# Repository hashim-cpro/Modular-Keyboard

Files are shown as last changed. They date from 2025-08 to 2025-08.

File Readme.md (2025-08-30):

<div align="center">
  <a href="https://hackclub.com/highway">
    
  </a>
  
<h1>60% Modular Keyboard</h1>
</div>

It is a 60% wireless keyboard(bluetooth) also works wired. It has magnetic modules. Currently I only added a Numpad but almost anything could be added in a chain as long as it works on i2c.
it has hotswapable switches, rgb lights for each key, OLED, rotoary encoder, dedicated charging module(1000mah) and a 10000mah battery. Also it is kind of MCU agnostic, you can use any XIAO series MCU with it, for example rp2040 if you don't want bluetooth or nRF52840.
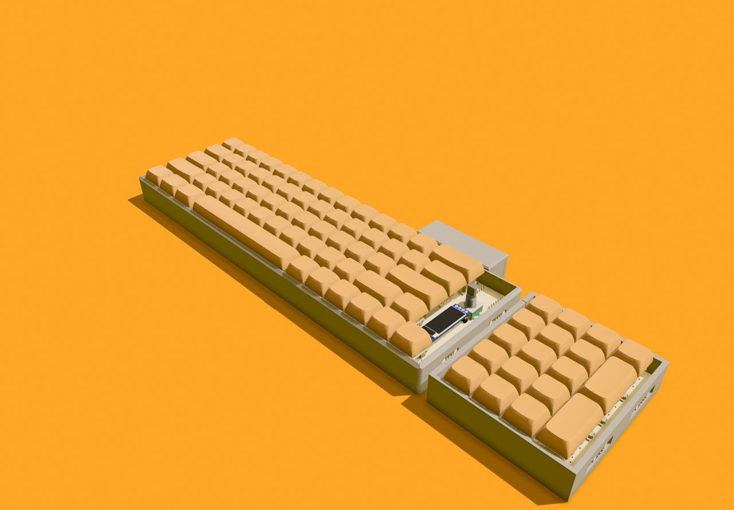
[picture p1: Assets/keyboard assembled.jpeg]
keyboard complete


# CAD Design

I used shapr3d to make the case, it is not done, I am still working on it, once I am happy with a case I will add it here, but the current case is as follows:
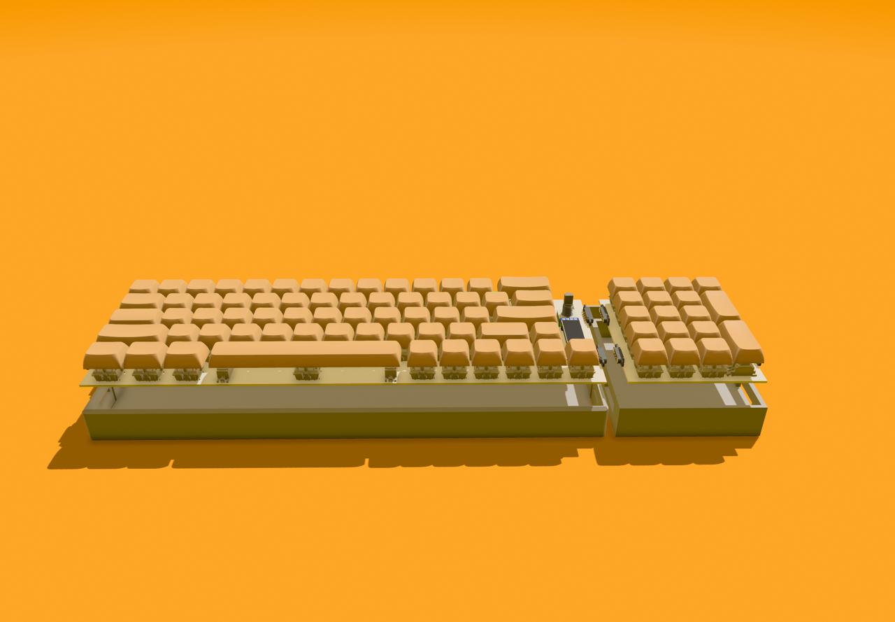
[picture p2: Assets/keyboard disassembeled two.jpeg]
keyboard disassembled

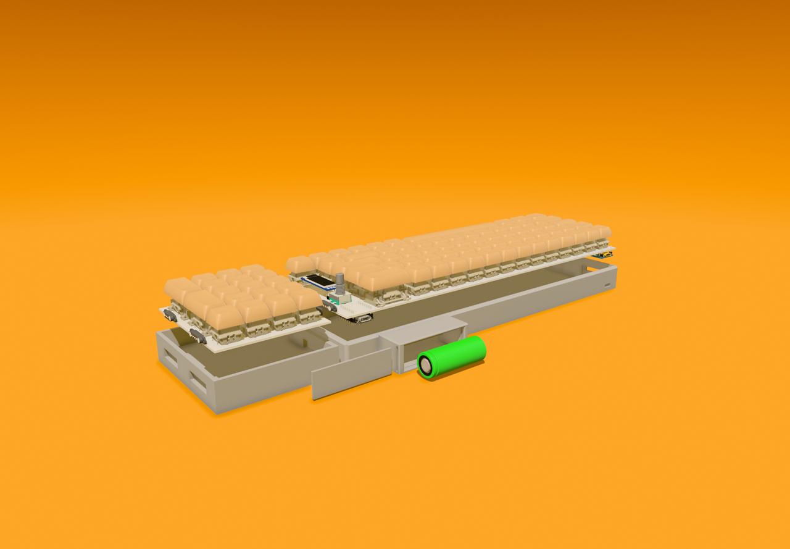
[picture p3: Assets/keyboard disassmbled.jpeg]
keyboard dissassembled


# Wired connections

The charging module and battery are not connected to the PCB electrically, I will use wires for them.
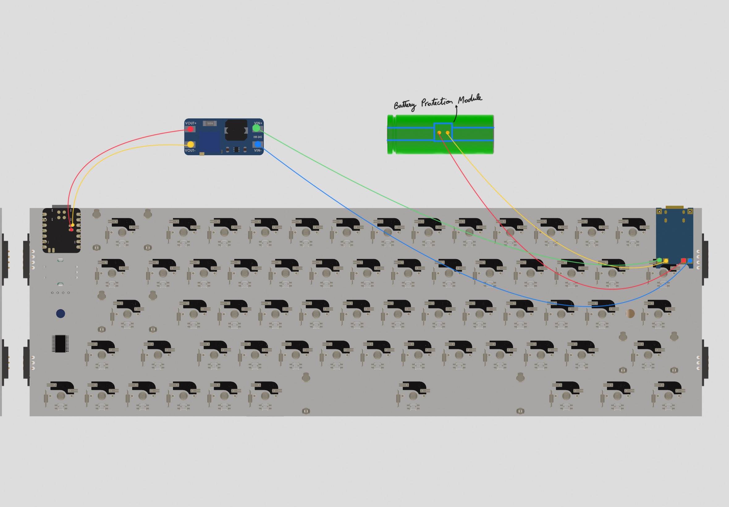
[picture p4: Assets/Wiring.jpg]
wiring


# PCB design

I used KiCad to make the PCB. Here are the schematics:

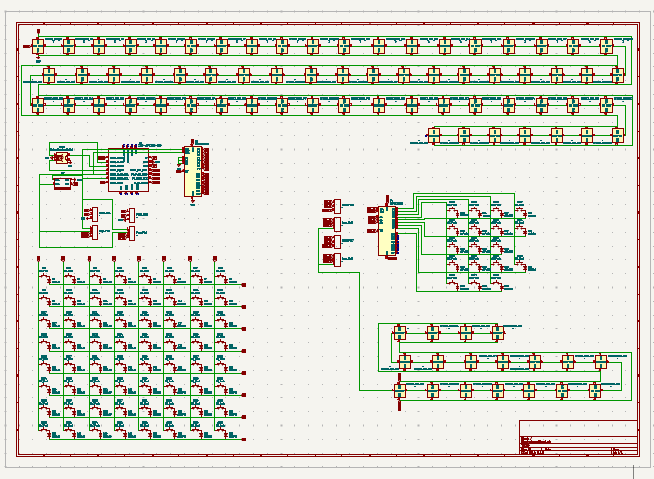
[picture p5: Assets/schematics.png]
schematics


Here is the PCB:
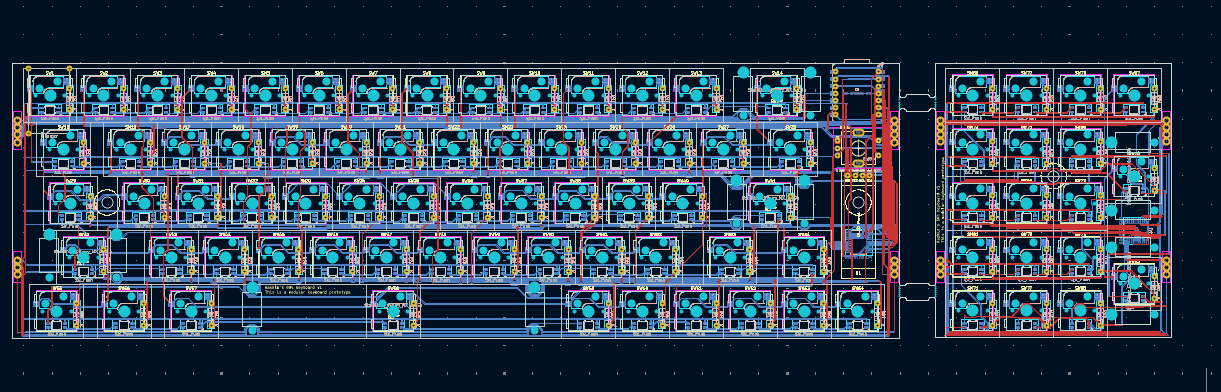
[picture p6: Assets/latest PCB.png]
PCB


# Firmware

For Firmware I made two versions:

1. **QMK Firmware**: Works out of the box but it is wired only (no Bluetooth). This is ready to use.
2. **ZMK Firmware**: Supports Bluetooth wireless functionality. This will work only when ZMK is upgraded to Zephyr 3.6 or with a custom driver for the I2C expander.

Both firmware options are available in this repository under the Firmware directory.

# BOM

here's the csv: [Link](https://docs.google.com/spreadsheets/d/1DyREVeE_MUjtT9r5M6x5S8JvudkvJUOvS-f6R7vg9m8/edit?usp=sharing)
| Name | Quantity | Price (USD) | Shipping Cost (USD) | URL |
| --- | --- | --- | --- | --- |
| [Switches](https://www.aliexpress.com/item/1005008458590123.html) | 90 | $35.73 | $0.00 | [Link](https://www.aliexpress.com/item/1005008458590123.html) |
| [Keycaps](https://www.aliexpress.com/item/1005006068241056.html) | 1 | $23.25 | $0.00 | [Link](https://www.aliexpress.com/item/1005006068241056.html) |
| [Hotswapable sockets](https://www.aliexpress.com/item/1005009187521124.html) | 110 | $15.39 | $0.00 | [Link](https://www.aliexpress.com/item/1005009187521124.html) |
| [Stabilizers](https://www.aliexpress.com/item/1005001686299616.html) | 1x set | $10.77 | $0.00 | [Link](https://www.aliexpress.com/item/1005001686299616.html) |
| Custom PCB | 5 | $20.00 | $25.00 | jlcpcb |
| [Magnetic pogo pins](https://www.aliexpress.com/item/1005008564171277.html) | 2x 3p and 2x 4p | $20.28 | $0.00 | [Link](https://www.aliexpress.com/item/1005008564171277.html) |
| [Microcontroller](https://www.aliexpress.com/item/1005007416714633.html) | 1 | $10.27 | $5.00 | [Link](https://www.aliexpress.com/item/1005007416714633.html) |
| [I2C expander](https://www.aliexpress.com/item/1005008705264264.html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) | 2 | $5.04 | $3.47 | [Link](https://www.aliexpress.com/item/1005008705264264.html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) |
| [Battery](https://www.aliexpress.com/item/1005001651303033.html) | 1 | $6.30 | $0.00 | [Link](https://www.aliexpress.com/item/1005001651303033.html) |
| [Battery protection module](https://www.aliexpress.com/item/1005007507131765.html) | 1 | $4.00 | $0.00 | [Link](https://www.aliexpress.com/item/1005007507131765.html) |
| Charging module | Will supply myself | $0.00 | $0.00 | - |
| Boost converter | Will supply myself | $0.00 | $0.00 | - |
| Rotatory Encoder | Already owned | $0.00 | $0.00 | - |
| [OLED module](https://www.aliexpress.com/item/1005006351390199.html) | 1 | $5.00 | $0.00 | [Link](https://www.aliexpress.com/item/1005006351390199.html) |
| [SK6812 mini E leds](https://www.aliexpress.com/item/1005008417206409.html) | 100 | $4.88 | $3.11 | [Link](https://www.aliexpress.com/item/1005008417206409.html) |
| [Diodes](https://digilog.pk/products/in4148-1n-4148-diode) | 100 | $1.00 | $1.00 | [Link](https://digilog.pk/products/in4148-1n-4148-diode) |
| **Total** | | **$161.55** | **$43.40** | |
| **Complete Cost** | | **$204.95** | | |

> The complete cost does not include the 3D printed case.

**Important Note**: You might find some of these components cheaper on AliExpress, but trust me, their shipping costs to Pakistan are absolutely insane. I created this BOM keeping Pakistani shipping costs in mind - sometimes paying a bit more upfront is way better than getting hit with crazy shipping fees later. If you're in a different country, definitely check AliExpress for better deals, but for us Pakistanis, this is probably your best bet cost-wise.

Also Ali Express prices tend to change for different regions, so when verifying the BOM, make sure to set the region to Pakistan to get the correct prices.

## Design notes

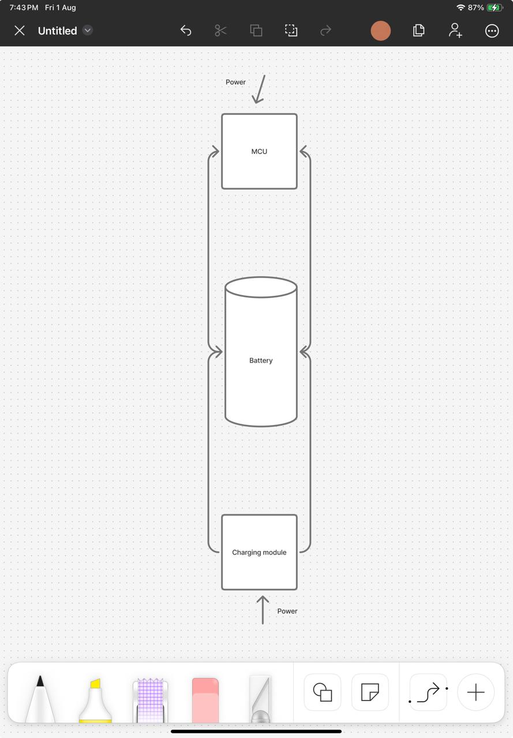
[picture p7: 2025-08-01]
Assets/wirting.jpeg

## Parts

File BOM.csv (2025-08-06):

Name | Quantity | Price | Shipping Cost | URL | Alternatives
Switches | 90 | 35.73 | 0 | https://www.aliexpress.com/item/1005008458590123.html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
keycaps | 1 | 23.25 | 0 | https://www.aliexpress.com/item/1005006068241056.html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
hotswapable sockets | 110 | 15.39 |  | https://www.aliexpress.com/item/1005009187521124.html?mp=1
stabalizers | 1x set | 10.77 | 0 | https://www.aliexpress.com/item/1005001686299616.html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
Custom PCB | 5 | 20 | 25 | jlcpcb
magnetic pogo pins | 2 3p and 2 4p | 20.28 | 0 | https://www.aliexpress.com/item/1005008564171277.html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
microcontroller | 1 | 10.27 | 5 | https://www.aliexpress.com/item/1005007416714633.html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 | https://www.aliexpress.com/item/1005009100619887.html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
I2C expander | 2 | 4.68 | 9.29 | https://lcsc.com/product-detail/I-O-Expanders_Texas-Instruments-PCF8575DBR_C2863388.html
battery | 1 | 6.3 | 0 | https://www.aliexpress.com/item/1005001651303033.html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 | https://www.multanelectronics.com/product/high-quality-3-7v-10000mah-1260110-polymer-lithium-ion-li-ion-rechargeable-battery-2/
Battery protection module | 1 | 4 | 0 | https://www.aliexpress.com/item/1005007507131765.html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 | https://www.aliexpress.com/w/wholesale--Li%2525252dIon-Battery-Protection-Board-BMS-1S-3A%252F.html
charging module | will supply myself | 0 |  | https://electrobes.com/product/tp4056-5v-micro-usb-1a-18650-lithium-battery-charging-board-charger-module/ | https://electrobes.com/product/tp4056-c-type-usb-port-1a-18650-lithium-battery-charging-board-charger-module/
Boost converter | will supply myself | 0 |  | https://electrobes.com/product/dc-dc-2a-adjustable-boost-power-supply-converter-step-up-module-2-24v/
Rotatory Encoder | already owned
OLED module | 1 | 5 | 0 | https://www.aliexpress.com/item/1005006351390199.html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
SK6812 mini E leds | 100 | 4.88 | 3.11 | https://www.aliexpress.com/item/1005008417206409.html?mp=1
Diodes | 100 | 1 | 1 | https://digilog.pk/products/in4148-1n-4148-diode
Total |  | 161.55 | 43.4
Complete Cost | 204.95

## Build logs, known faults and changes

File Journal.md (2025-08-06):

---
title: Modular Keyboard
author: Hashim
description: "A 60% modular keyboard wireless/wired with per key RGB, OLED, rotatry encoder, and magnetically attachable modules and more."
created_at: July 31st, 2025
---

**Total Time Spent: 40-48 Hours**

> but take it with a pinch of salt, I didn't keep track of time properly, I probably spent way more then that researching, designing, debugging, repeating, and redoing everything. So this is just the minimum time I think I spent on this project.

# Day 1: Research - July 22nd

**Time Spent: [3-4] hours**

So I want a minimal keyboard but I also love using numpad and more keys or inputs. On this day I watched this video which inspired me to make it.

**Inspiration Video:** [DIY Modular Macropad](https://www.youtube.com/watch?v=7DfexfHzT-w&list=LL&index=6&t=8s)

YouTube Video (https://www.youtube.com/watch?v=7DfexfHzT-w&list=LL&index=6&t=8s)

He made a modular macropad and used the I2C protocol to communicate with the modules. I thought it was a good idea and I will use the same protocol to communicate with my modules.
This guy made a mistake by using a common interrupt key throughout all the modules but I will use different interrupt keys for modules {future me here, that didn't happen because I ran out of GPIOs.🥲}

Now it's time to decide which modules I will have for my keyboard. I have decided that I want to have somewhat a 60% keyboard layout on the main keyboard and have the modules attachable on both sides. So I went for this layout for the main keyboard.

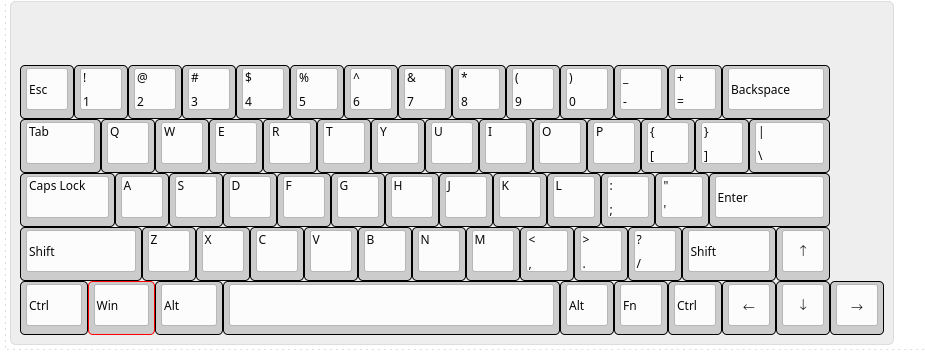
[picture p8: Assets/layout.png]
Main Keyboard Layout


And for numpad I will have 18 keys as follows:
It has an extra key than the standard numpad layout because I don't want a big ass 0 key.

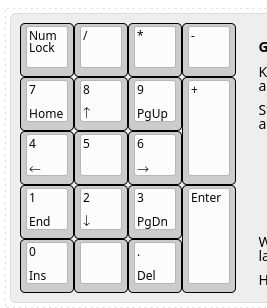
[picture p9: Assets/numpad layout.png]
Numpad Layout


Okay so I know how to make a wired keyboard, I just made a [Wired hackpad](https://github.com/hashim-cpro/hackpad) but how do I make a wireless keyboard. Let's Google it or Gemini it actually.

Okay so it seems like this nice nano board is quite popular for making wireless keyboards but there is a problem.
It works on 3.3V power and logic which would not be enough to run or control our RGB and peripherals. Also it is big, I want a minimal keyboard.
But maybe there are work arounds for that so let's just go for it since it has a good community support and was built for this specific purpose but for god's sake all the sellers that sell it have very high shipping rates for me. I have to keep things in budget, I found the alternatives for this board on AliExpress but they were a bit sus so I went with Seeed XIAO nRF52840, it has less GPIO pins but we can work around that with I2C expanders but it is really small which is good.

# Day 2: Schematics - July 23rd

**Time Spent: [5] hours**

Okay so let's make the schematics for the main keyboard.

Schematics

{This was not the first version, this is the final one, I made a lot of changes to the schematics because I did it wrong a couple of times and had to redo it that's why it took me so long + i kept making changes as i was learning and finding new components that I wanted to use.}

# Day 3: PCB Design - July 24th

**Time Spent: [5] hours**

Okay I made the whole PCB of the main keyboard in KiCad but then a sudden realization occurred to me after watching someone on YouTube soldering hotswappable sockets on the PCB. I was like wait a minute, I can do that too. So I went back to the PCB and changed the footprints of the switches to hotswappable sockets. But then almost all of my routing which literally took me hours to do was gone. I was like noooooo, so I had to route the whole PCB again.

Here was the before PCB without sockets:

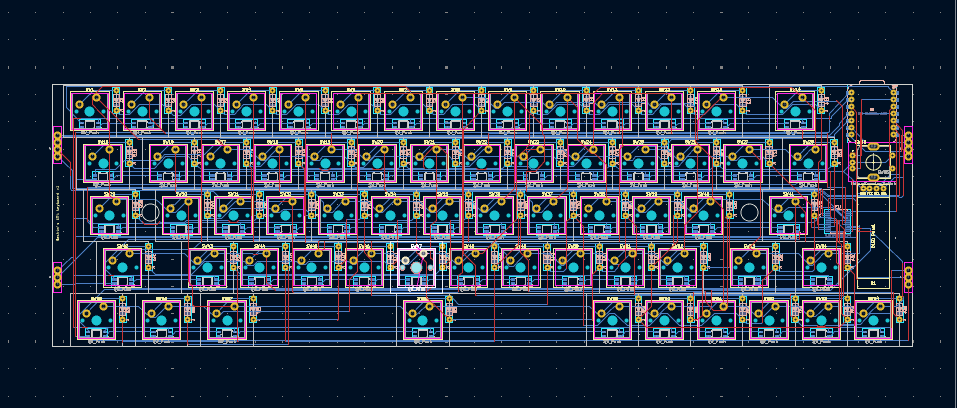
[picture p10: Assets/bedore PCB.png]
Before PCB


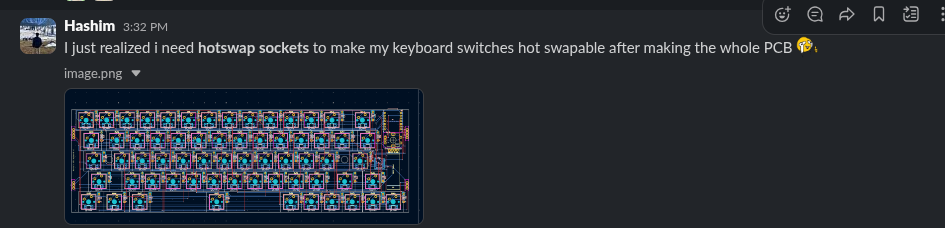
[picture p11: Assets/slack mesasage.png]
Slack Message


Then I was like fuck this shit.

# Day 4: PCB Routing Continued + firmware - July 28th-29th-30th, 2024

**Time Spent: [10-15] hours**

Probably gotta re-route the whole thing so add the numpad in the schematic. I hadn't addded the numpad before

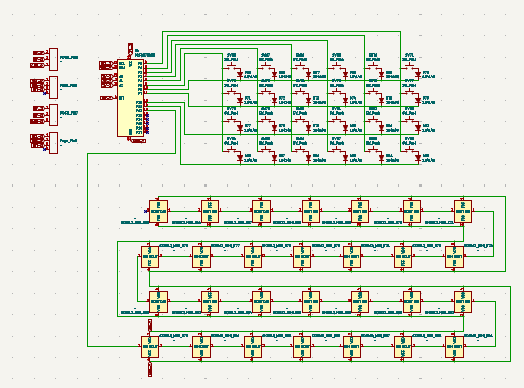
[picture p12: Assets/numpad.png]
Numpad Schematic

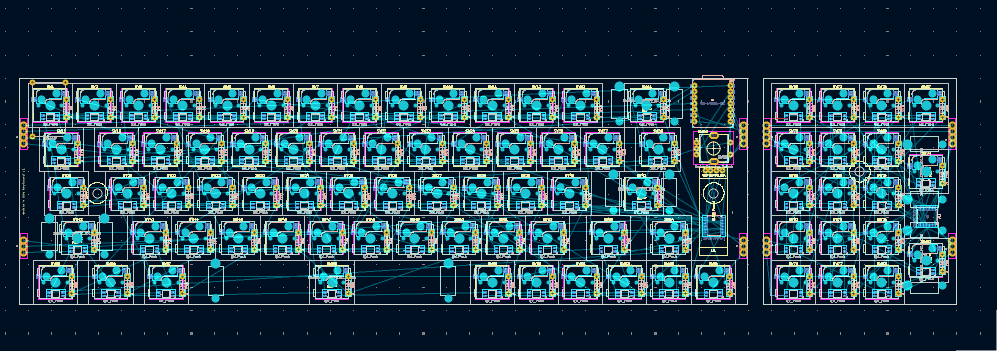
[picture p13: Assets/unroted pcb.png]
unrouted PCB

After that I routed the whole PCB again. I also learned that it is okay if you don't follow the schematic wiring layout strictly as the PCB editor is right to tell you to share common tracks. I DIDN"T KNEW THAT, I thought it may short circuit or something but then after some hours I realised how dumb i was to do this, this made routing so hard for me previously because i used to just verify each route from the schematic. But anyways I caught up and re routed the whole thing

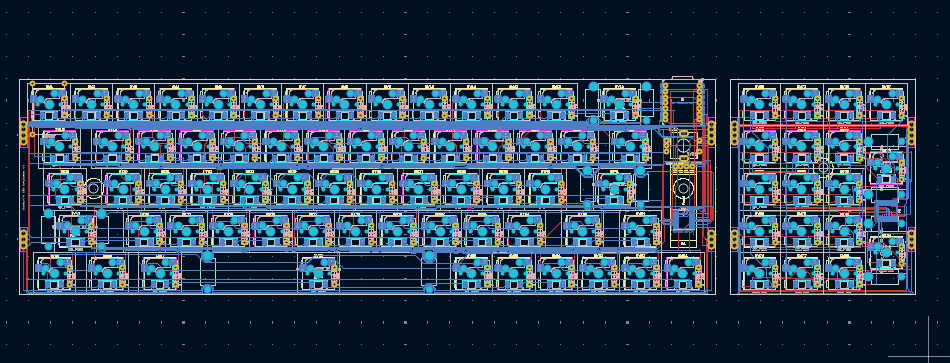
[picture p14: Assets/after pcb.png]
After PCB


There were some errors with the footprint library I was using for my LEDs, solved them and then modified the board outline and was all done with PCB:

Latest PCB

**Time Spent: [9] hours**

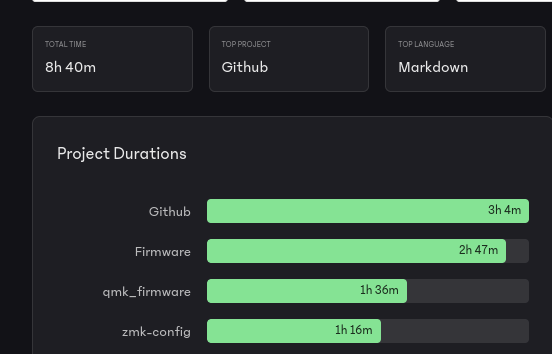
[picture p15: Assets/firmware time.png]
Firmware time


For firmware I wanted to make both QMK and ZMK but QMK doesn't support my board and I came to know that when I wrote the whole thing, god dang it.

Then I went for ZMK, I knew that ZMK was based on Zephyr so i automatically assumed that it would have support for all my peripherals, turns out it didn't for one main component which is our I2C expander, there were no drivers for it in ZMK but there are in Zephyr, ZMK uses 3.5 and support for them were added in 3.6 Zephyr which means we don't have to redo the whole thing again (god knows how many times I just got frustrated and wanted to give up) KiCad was not cooperating with me, it was crashing all the time, I had to restart it like 10 times in a day. But anyway I hope for the best and I will try to make the firmware work with ZMK, if not then I will hack together a driver for the I2C expander. I tried to in the current version but I am not sure if it will work. But anyways wait a little bit and then we will have ZMK support built in for the I2C expander. Probably that would be before even my parts arrive. So no worries. Anyways firmware is kinda boring, we can debug it once we have the parts and the PCB in hand. And if all that didn't work (which is almost impossible) then we can always use the Arduino framework to make it work. I can't test it because I don't have the parts yet but I am sure it will work out + QMK firmware for RP2040 might work out of the box, I will try that too. (I am skeptical about it though because only a random user on Reddit claims to have it working)

> Edit: I just realized that my PCB is MCU agnostic, well kind of, I can use and MCU from XIAO series so I can choose rp2040 or nRF52840, it is upto you (highway reviewer) should I get rp2040 and just use QMK or get nRF52840 and use ZMK, and hope that until the parts arrive, ZMK would have shifted to Zephyr 3.6 and have support for the I2C expander, if not then I will hack together a driver for it.

# Day 5: Case Design - July 31th, 2024

**Time Spent: [5-7] hours**

Now for the case, I made it in Shapr3D, it was kind of a rush job because I had to make it in a day, so I made it in a day, it was not that hard, I just made the case for the main keyboard and the numpad, I might want to change the battery from Li-ion to Li-Po because it is more compact and has more capacity, but I will see about that later.

Now the case building progress:

I wanted a minimal case but before making the case I tried to export the PCB to Shapr3D but for some reason the export was like a logic bomb from KiCad, it crashed Shapr3D every time, I had to try multiple formats and then finally STL worked. This was the most frustration that I got in this project, I had to make the case from scratch like 3 times because of this. Now time to add the remaining peripherals on PCB like most importantly the magnetic pogo pins because they had to be aligned and supported well, I couldn't find a 3D model for my specific pogo pins that I was using so I had to make it myself, it was not that hard.

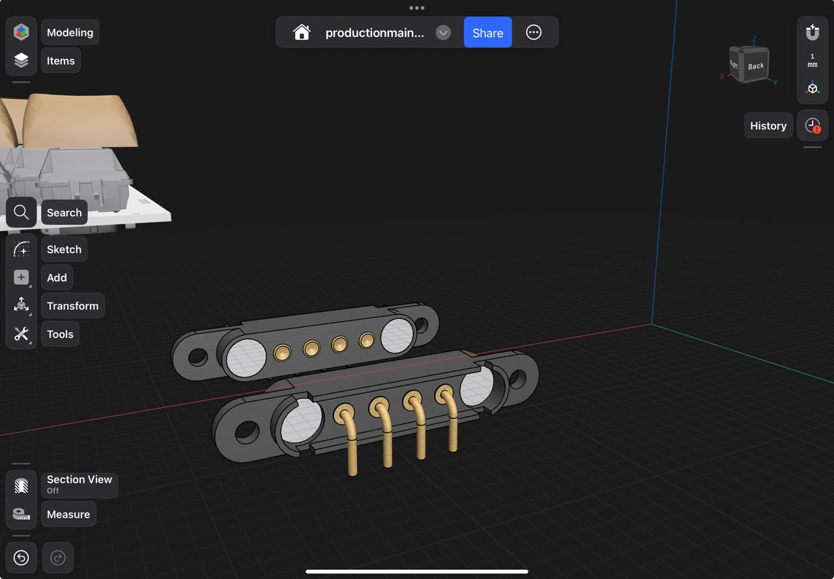
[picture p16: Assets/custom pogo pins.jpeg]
Custom Pogo Pins


Now all of my peripherals were in place and I was ready to make the case, I made the case in Shapr3D, it was not that hard, I just had to make sure that all the peripherals were in place and aligned properly.

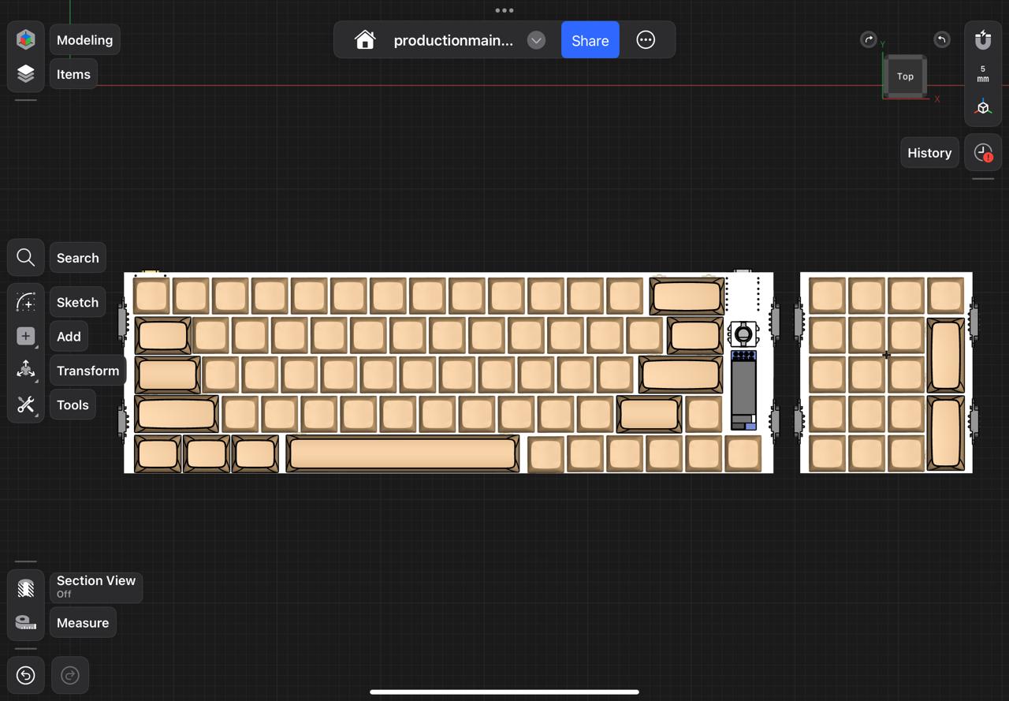
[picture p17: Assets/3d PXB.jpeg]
3D PCB


Keyboard Assembled

Keyboard Disassembled

Keyboard Disassembled Two

I am still not sure about the case, I may change it later, but for now it is good enough for submission.

FYI I am working on it at the moment and will update the readme once I am done with it.

I placed the MCU in the bottom using these pins, IDK what to call them.

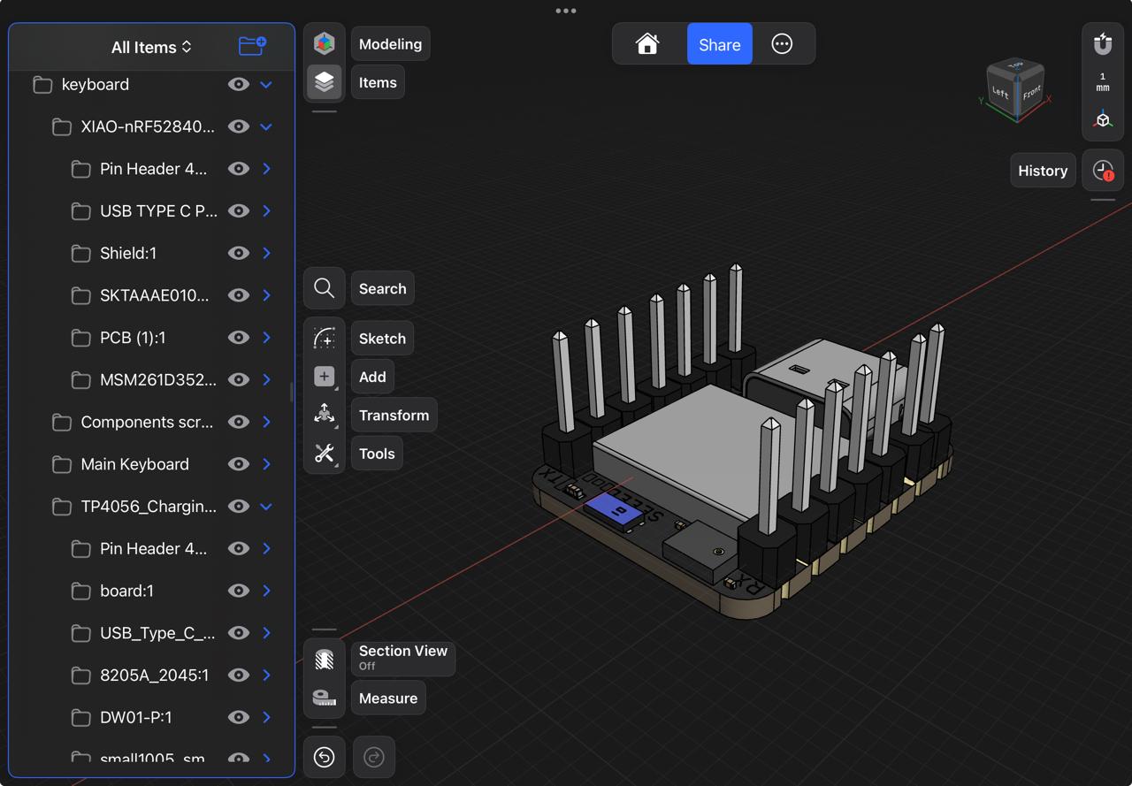
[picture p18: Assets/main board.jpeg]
Main Board


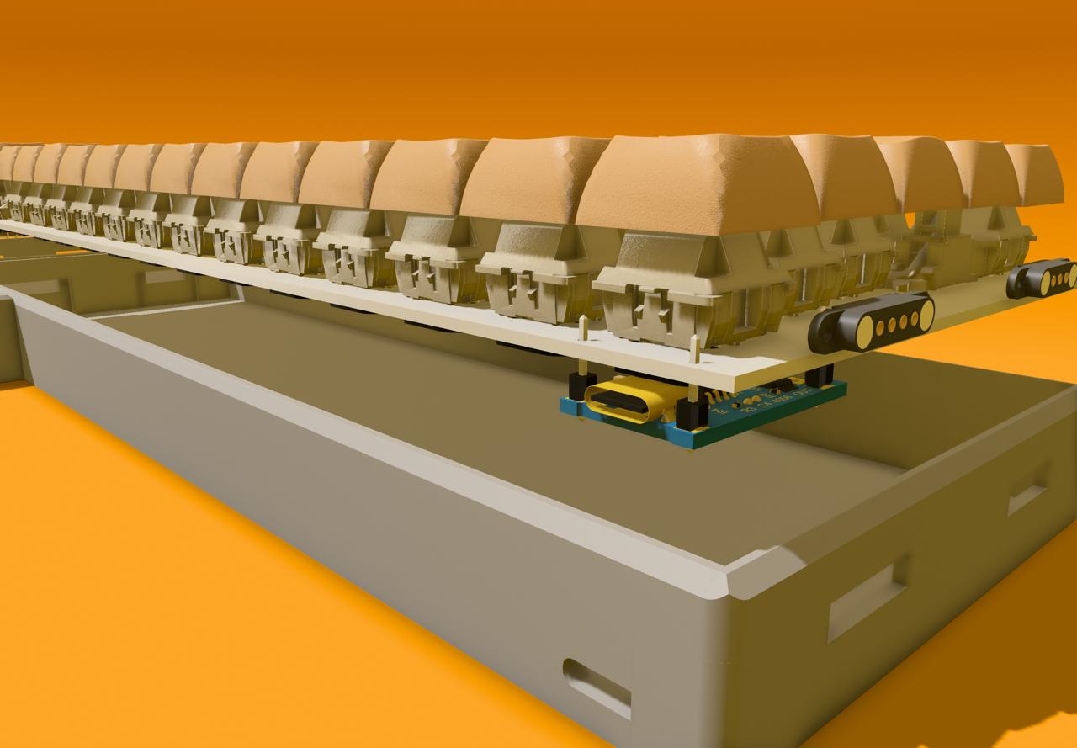
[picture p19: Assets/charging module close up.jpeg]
Charging Module Close Up


Now you might be wondering why the battery and charging module are not connected anywhere in the PCB or the MCU, it's because of a weird positioning of the battery pads in the MCU. I am new to soldering so I thought just use those pins to lift up the MCU a little from the board and use wire to connect the battery and charging module to the MCU. So yes it is intentional that the battery and charging module are not connected to the PCB, anywhere in the schematic and PCB.

# day idk

i just spent 3 hours making the BOM mostly searching for the components cheaper with free shiping and stuff
i also realized a major problem with the curtrentyy battery circuit had to do xsome research and made a wiring diagram

# Wiring diagram

Wiring Diagram

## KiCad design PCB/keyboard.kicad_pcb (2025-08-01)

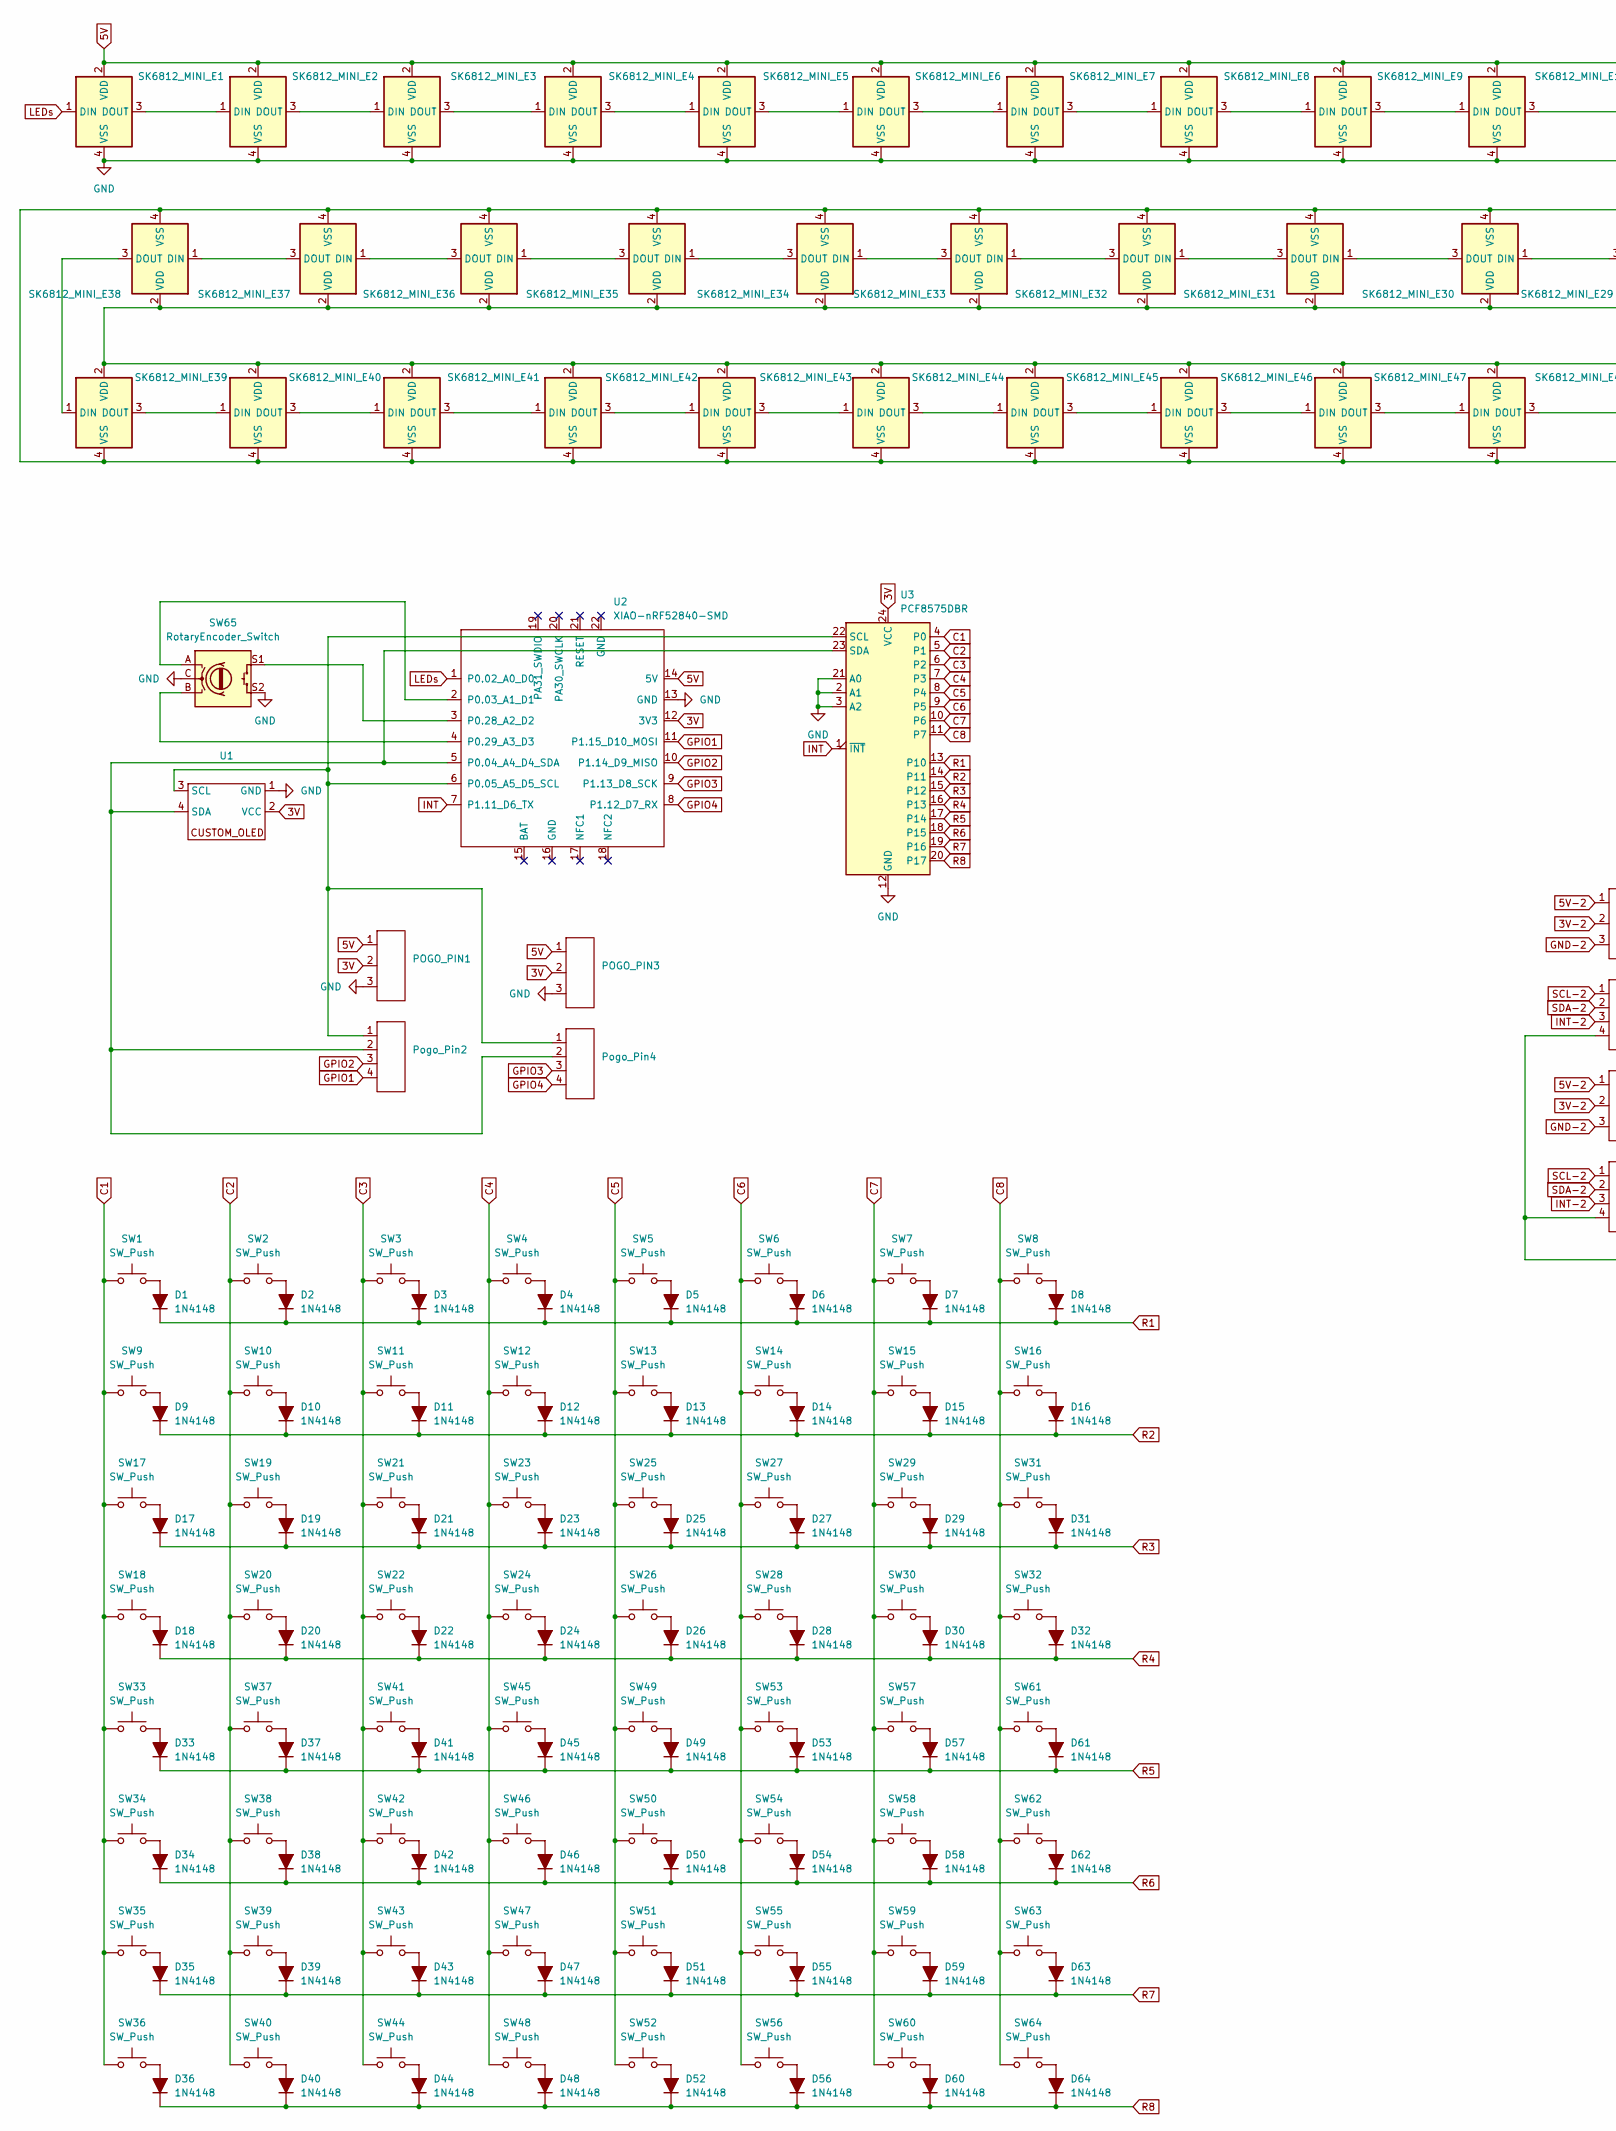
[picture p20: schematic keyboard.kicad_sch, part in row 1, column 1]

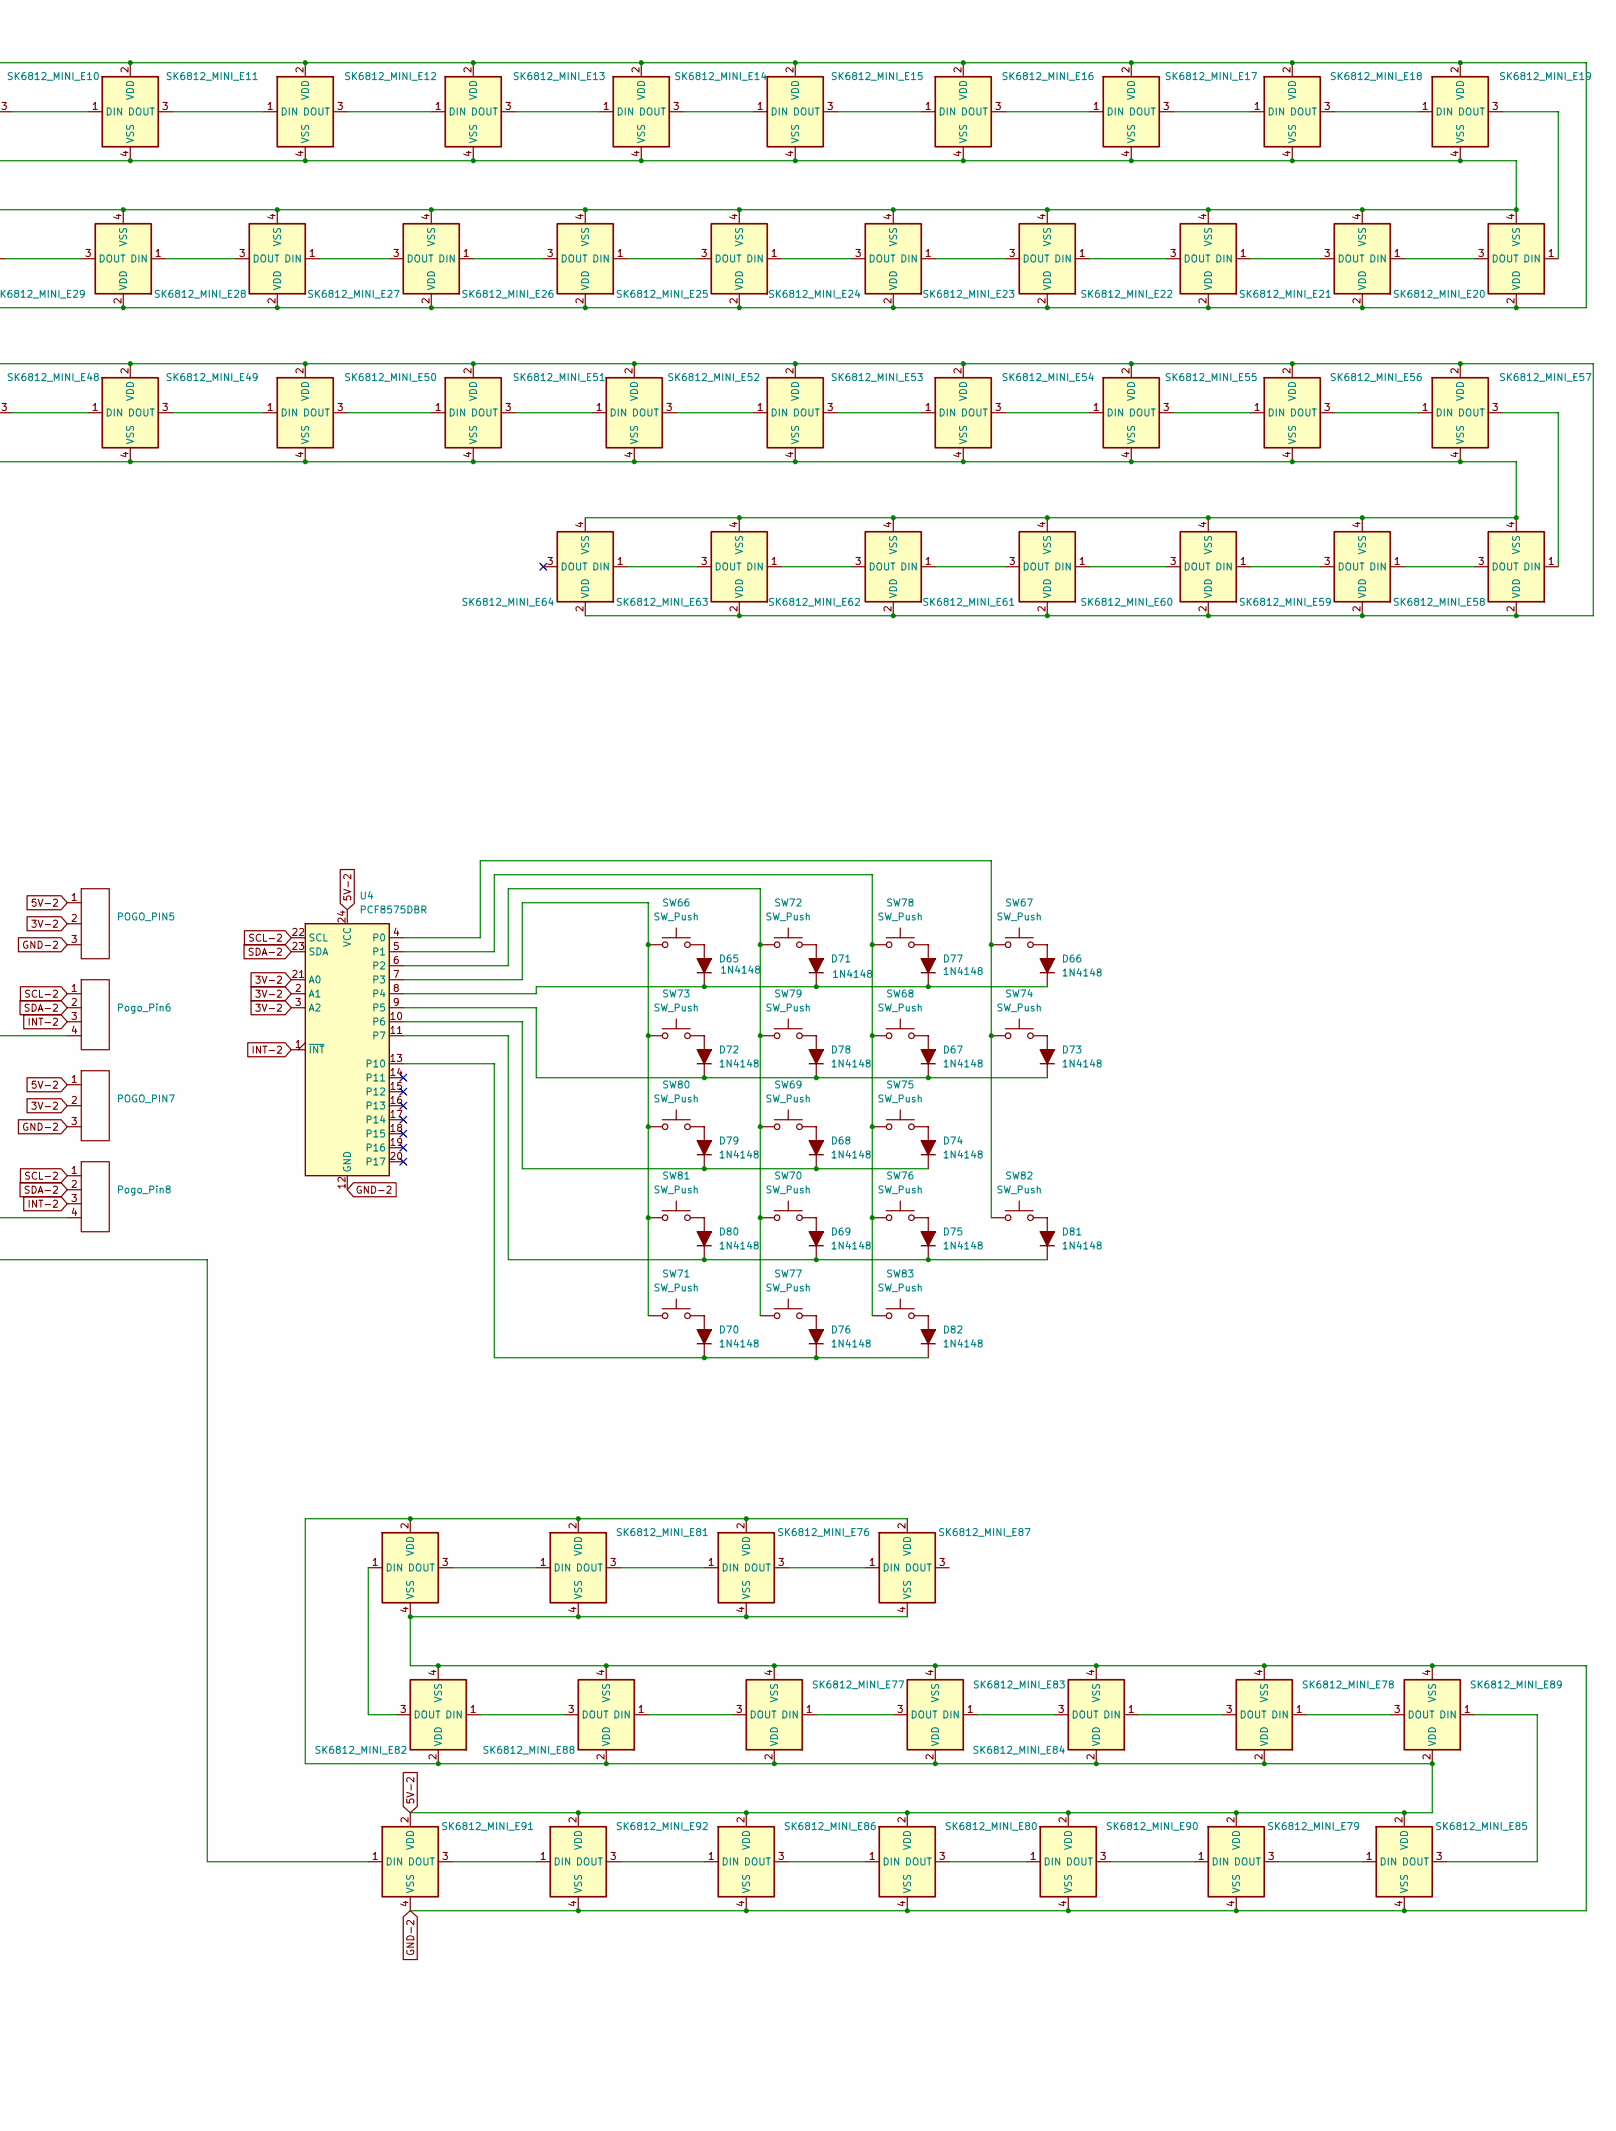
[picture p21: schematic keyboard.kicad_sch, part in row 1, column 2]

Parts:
D1, D2, D3, D4, D5, D6, D7, D8, D9, D10, D11, D12, D13, D14, D15, D16, D17, D18, D19, D20, D21, D22, D23, D24, D25, D26, D27, D28, D29, D30, D31, D32, D33, D34, D35, D36, D37, D38, D39, D40, D41, D42, D43, D44, D45, D46, D47, D48, D49, D50, D51, D52, D53, D54, D55, D56, D57, D58, D59, D60, D61, D62, D63, D64, D65, D66, D67, D68, D69, D70, D71, D72, D73, D74, D75, D76, D77, D78, D79, D80, D81, D82: 1N4148; D_DO-35_SOD27_P7.62mm_Horizontal
POGO_PIN1, POGO_PIN3, POGO_PIN5, POGO_PIN7: Pogo_Pins_3P
Pogo_Pin2, Pogo_Pin4, Pogo_Pin6, Pogo_Pin8: Pogo_Pins_4P
SK6812_MINI_E1, SK6812_MINI_E2, SK6812_MINI_E3, SK6812_MINI_E4, SK6812_MINI_E5, SK6812_MINI_E6, SK6812_MINI_E7, SK6812_MINI_E8, SK6812_MINI_E9, SK6812_MINI_E10, SK6812_MINI_E11, SK6812_MINI_E12, SK6812_MINI_E13, SK6812_MINI_E14, SK6812_MINI_E15, SK6812_MINI_E16, SK6812_MINI_E17, SK6812_MINI_E18, SK6812_MINI_E19, SK6812_MINI_E20, SK6812_MINI_E21, SK6812_MINI_E22, SK6812_MINI_E23, SK6812_MINI_E24, SK6812_MINI_E25, SK6812_MINI_E26, SK6812_MINI_E27, SK6812_MINI_E28, SK6812_MINI_E29, SK6812_MINI_E30, SK6812_MINI_E31, SK6812_MINI_E32, SK6812_MINI_E33, SK6812_MINI_E34, SK6812_MINI_E35, SK6812_MINI_E36, SK6812_MINI_E37, SK6812_MINI_E38, SK6812_MINI_E39, SK6812_MINI_E40, SK6812_MINI_E41, SK6812_MINI_E42, SK6812_MINI_E43, SK6812_MINI_E44, SK6812_MINI_E45, SK6812_MINI_E46, SK6812_MINI_E47, SK6812_MINI_E48, SK6812_MINI_E49, SK6812_MINI_E50, SK6812_MINI_E51, SK6812_MINI_E52, SK6812_MINI_E53, SK6812_MINI_E54, SK6812_MINI_E55, SK6812_MINI_E56, SK6812_MINI_E57, SK6812_MINI_E58, SK6812_MINI_E59, SK6812_MINI_E60, SK6812_MINI_E61, SK6812_MINI_E62, SK6812_MINI_E63, SK6812_MINI_E64, SK6812_MINI_E75, SK6812_MINI_E76, SK6812_MINI_E77, SK6812_MINI_E78, SK6812_MINI_E79, SK6812_MINI_E80, SK6812_MINI_E81, SK6812_MINI_E82, SK6812_MINI_E83, SK6812_MINI_E84, SK6812_MINI_E85, SK6812_MINI_E86, SK6812_MINI_E87, SK6812_MINI_E88, SK6812_MINI_E89, SK6812_MINI_E90, SK6812_MINI_E91, SK6812_MINI_E92: MX_SK6812MINI-E
SW1, SW2, SW3, SW4, SW5, SW6, SW7, SW8, SW9, SW10, SW11, SW12, SW13, SW14, SW15, SW16, SW17, SW18, SW19, SW20, SW21, SW22, SW23, SW24, SW25, SW26, SW27, SW28, SW29, SW30, SW31, SW32, SW33, SW34, SW35, SW36, SW37, SW38, SW39, SW40, SW41, SW42, SW43, SW44, SW45, SW46, SW47, SW48, SW49, SW50, SW51, SW52, SW53, SW54, SW55, SW56, SW57, SW58, SW59, SW60, SW61, SW62, SW63, SW64, SW66, SW67, SW68, SW69, SW70, SW71, SW72, SW73, SW74, SW75, SW76, SW77, SW78, SW79, SW80, SW81, SW82, SW83: SW_Push; SW_Hotswap_Kailh_MX_1.00u
SW65: RotaryEncoder_Switch; RotaryEncoder_Alps_EC11E-Switch_Vertical_H20mm
U1: SSD1306-0.91-OLED-4pin-128x32
U2: XIAO-nRF52840-SMD; XIAO-nRF52840-DIP
U3, U4: PCF8575DBR; SSOP-24_5.3x8.2mm_P0.65mm

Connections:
3V: POGO_PIN1.2, POGO_PIN3.2, U1.2 (VCC), U2.12 (3V3), U3.24 (VCC)
3V-2: POGO_PIN5.2, POGO_PIN7.2, U4.2 (A1), U4.3 (A2), U4.21 (A0)
5V: POGO_PIN1.1, POGO_PIN3.1, SK6812_MINI_E1.2 (VDD), SK6812_MINI_E2.2 (VDD), SK6812_MINI_E3.2 (VDD), SK6812_MINI_E4.2 (VDD), SK6812_MINI_E5.2 (VDD), SK6812_MINI_E6.2 (VDD), SK6812_MINI_E7.2 (VDD), SK6812_MINI_E8.2 (VDD), SK6812_MINI_E9.2 (VDD), SK6812_MINI_E10.2 (VDD), SK6812_MINI_E11.2 (VDD), SK6812_MINI_E12.2 (VDD), SK6812_MINI_E13.2 (VDD), SK6812_MINI_E14.2 (VDD), SK6812_MINI_E15.2 (VDD), SK6812_MINI_E16.2 (VDD), SK6812_MINI_E17.2 (VDD), SK6812_MINI_E18.2 (VDD), SK6812_MINI_E19.2 (VDD), SK6812_MINI_E20.2 (VDD), SK6812_MINI_E21.2 (VDD), SK6812_MINI_E22.2 (VDD), SK6812_MINI_E23.2 (VDD), SK6812_MINI_E24.2 (VDD), SK6812_MINI_E25.2 (VDD), SK6812_MINI_E26.2 (VDD), SK6812_MINI_E27.2 (VDD), SK6812_MINI_E28.2 (VDD), SK6812_MINI_E29.2 (VDD), SK6812_MINI_E30.2 (VDD), SK6812_MINI_E31.2 (VDD), SK6812_MINI_E32.2 (VDD), SK6812_MINI_E33.2 (VDD), SK6812_MINI_E34.2 (VDD), SK6812_MINI_E35.2 (VDD), SK6812_MINI_E36.2 (VDD), SK6812_MINI_E37.2 (VDD), SK6812_MINI_E38.2 (VDD), SK6812_MINI_E39.2 (VDD), SK6812_MINI_E40.2 (VDD), SK6812_MINI_E41.2 (VDD), SK6812_MINI_E42.2 (VDD), SK6812_MINI_E43.2 (VDD), SK6812_MINI_E44.2 (VDD), SK6812_MINI_E45.2 (VDD), SK6812_MINI_E46.2 (VDD), SK6812_MINI_E47.2 (VDD), SK6812_MINI_E48.2 (VDD), SK6812_MINI_E49.2 (VDD), SK6812_MINI_E50.2 (VDD), SK6812_MINI_E51.2 (VDD), SK6812_MINI_E52.2 (VDD), SK6812_MINI_E53.2 (VDD), SK6812_MINI_E54.2 (VDD), SK6812_MINI_E55.2 (VDD), SK6812_MINI_E56.2 (VDD), SK6812_MINI_E57.2 (VDD), SK6812_MINI_E58.2 (VDD), SK6812_MINI_E59.2 (VDD), SK6812_MINI_E60.2 (VDD), SK6812_MINI_E61.2 (VDD), SK6812_MINI_E62.2 (VDD), SK6812_MINI_E63.2 (VDD), SK6812_MINI_E64.2 (VDD), U2.14 (5V)
5V-2: POGO_PIN5.1, POGO_PIN7.1, SK6812_MINI_E75.2 (VDD), SK6812_MINI_E76.2 (VDD), SK6812_MINI_E77.2 (VDD), SK6812_MINI_E78.2 (VDD), SK6812_MINI_E79.2 (VDD), SK6812_MINI_E80.2 (VDD), SK6812_MINI_E81.2 (VDD), SK6812_MINI_E82.2 (VDD), SK6812_MINI_E83.2 (VDD), SK6812_MINI_E84.2 (VDD), SK6812_MINI_E85.2 (VDD), SK6812_MINI_E86.2 (VDD), SK6812_MINI_E87.2 (VDD), SK6812_MINI_E88.2 (VDD), SK6812_MINI_E89.2 (VDD), SK6812_MINI_E90.2 (VDD), SK6812_MINI_E91.2 (VDD), SK6812_MINI_E92.2 (VDD), U4.24 (VCC)
C1: SW1.1, SW9.1, SW17.1, SW18.1, SW33.1, SW34.1, SW35.1, SW36.1, U3.4 (P0)
C2: SW2.1, SW10.1, SW19.1, SW20.1, SW37.1, SW38.1, SW39.1, SW40.1, U3.5 (P1)
C3: SW3.1, SW11.1, SW21.1, SW22.1, SW41.1, SW42.1, SW43.1, SW44.1, U3.6 (P2)
C4: SW4.1, SW12.1, SW23.1, SW24.1, SW45.1, SW46.1, SW47.1, SW48.1, U3.7 (P3)
C5: SW5.1, SW13.1, SW25.1, SW26.1, SW49.1, SW50.1, SW51.1, SW52.1, U3.8 (P4)
C6: SW6.1, SW14.1, SW27.1, SW28.1, SW53.1, SW54.1, SW55.1, SW56.1, U3.9 (P5)
C7: SW7.1, SW15.1, SW29.1, SW30.1, SW57.1, SW58.1, SW59.1, SW60.1, U3.10 (P6)
C8: SW8.1, SW16.1, SW31.1, SW32.1, SW61.1, SW62.1, SW63.1, SW64.1, U3.11 (P7)
GND: POGO_PIN1.3, POGO_PIN3.3, SK6812_MINI_E1.4 (VSS), SK6812_MINI_E2.4 (VSS), SK6812_MINI_E3.4 (VSS), SK6812_MINI_E4.4 (VSS), SK6812_MINI_E5.4 (VSS), SK6812_MINI_E6.4 (VSS), SK6812_MINI_E7.4 (VSS), SK6812_MINI_E8.4 (VSS), SK6812_MINI_E9.4 (VSS), SK6812_MINI_E10.4 (VSS), SK6812_MINI_E11.4 (VSS), SK6812_MINI_E12.4 (VSS), SK6812_MINI_E13.4 (VSS), SK6812_MINI_E14.4 (VSS), SK6812_MINI_E15.4 (VSS), SK6812_MINI_E16.4 (VSS), SK6812_MINI_E17.4 (VSS), SK6812_MINI_E18.4 (VSS), SK6812_MINI_E19.4 (VSS), SK6812_MINI_E20.4 (VSS), SK6812_MINI_E21.4 (VSS), SK6812_MINI_E22.4 (VSS), SK6812_MINI_E23.4 (VSS), SK6812_MINI_E24.4 (VSS), SK6812_MINI_E25.4 (VSS), SK6812_MINI_E26.4 (VSS), SK6812_MINI_E27.4 (VSS), SK6812_MINI_E28.4 (VSS), SK6812_MINI_E29.4 (VSS), SK6812_MINI_E30.4 (VSS), SK6812_MINI_E31.4 (VSS), SK6812_MINI_E32.4 (VSS), SK6812_MINI_E33.4 (VSS), SK6812_MINI_E34.4 (VSS), SK6812_MINI_E35.4 (VSS), SK6812_MINI_E36.4 (VSS), SK6812_MINI_E37.4 (VSS), SK6812_MINI_E38.4 (VSS), SK6812_MINI_E39.4 (VSS), SK6812_MINI_E40.4 (VSS), SK6812_MINI_E41.4 (VSS), SK6812_MINI_E42.4 (VSS), SK6812_MINI_E43.4 (VSS), SK6812_MINI_E44.4 (VSS), SK6812_MINI_E45.4 (VSS), SK6812_MINI_E46.4 (VSS), SK6812_MINI_E47.4 (VSS), SK6812_MINI_E48.4 (VSS), SK6812_MINI_E49.4 (VSS), SK6812_MINI_E50.4 (VSS), SK6812_MINI_E51.4 (VSS), SK6812_MINI_E52.4 (VSS), SK6812_MINI_E53.4 (VSS), SK6812_MINI_E54.4 (VSS), SK6812_MINI_E55.4 (VSS), SK6812_MINI_E56.4 (VSS), SK6812_MINI_E57.4 (VSS), SK6812_MINI_E58.4 (VSS), SK6812_MINI_E59.4 (VSS), SK6812_MINI_E60.4 (VSS), SK6812_MINI_E61.4 (VSS), SK6812_MINI_E62.4 (VSS), SK6812_MINI_E63.4 (VSS), SK6812_MINI_E64.4 (VSS), SW65.C, SW65.S2, U1.1 (GND), U2.13 (GND), U3.2 (A1), U3.3 (A2), U3.12 (GND), U3.21 (A0)
GND-2: POGO_PIN5.3, POGO_PIN7.3, SK6812_MINI_E75.4 (VSS), SK6812_MINI_E76.4 (VSS), SK6812_MINI_E77.4 (VSS), SK6812_MINI_E78.4 (VSS), SK6812_MINI_E79.4 (VSS), SK6812_MINI_E80.4 (VSS), SK6812_MINI_E81.4 (VSS), SK6812_MINI_E82.4 (VSS), SK6812_MINI_E83.4 (VSS), SK6812_MINI_E84.4 (VSS), SK6812_MINI_E85.4 (VSS), SK6812_MINI_E86.4 (VSS), SK6812_MINI_E87.4 (VSS), SK6812_MINI_E88.4 (VSS), SK6812_MINI_E89.4 (VSS), SK6812_MINI_E90.4 (VSS), SK6812_MINI_E91.4 (VSS), SK6812_MINI_E92.4 (VSS), U4.12 (GND)
GPIO1: Pogo_Pin2.4, U2.11 (P1.15_D10_MOSI)
GPIO2: Pogo_Pin2.3, U2.10 (P1.14_D9_MISO)
GPIO3: Pogo_Pin4.3, U2.9 (P1.13_D8_SCK)
GPIO4: Pogo_Pin4.4, U2.8 (P1.12_D7_RX)
INT: U2.7 (P1.11_D6_TX), U3.1 (~INT)
INT-2: Pogo_Pin6.3, Pogo_Pin8.3, U4.1 (~INT)
LEDs: SK6812_MINI_E1.1 (DIN), U2.1 (P0.02_A0_D0)
unnamed: D1.2 (A), SW1.2
unnamed: D2.2 (A), SW2.2
unnamed: D3.2 (A), SW3.2
unnamed: D4.2 (A), SW4.2
unnamed: D5.2 (A), SW5.2
unnamed: D6.2 (A), SW6.2
unnamed: D7.2 (A), SW7.2
unnamed: D8.2 (A), SW8.2
unnamed: D9.2 (A), SW9.2
unnamed: D10.2 (A), SW10.2
unnamed: D11.2 (A), SW11.2
unnamed: D12.2 (A), SW12.2
unnamed: D13.2 (A), SW13.2
unnamed: D14.2 (A), SW14.2
unnamed: D15.2 (A), SW15.2
unnamed: D16.2 (A), SW16.2
unnamed: D17.2 (A), SW17.2
unnamed: D18.2 (A), SW18.2
unnamed: D19.2 (A), SW19.2
unnamed: D20.2 (A), SW20.2
unnamed: D21.2 (A), SW21.2
unnamed: D22.2 (A), SW22.2
unnamed: D23.2 (A), SW23.2
unnamed: D24.2 (A), SW24.2
unnamed: D25.2 (A), SW25.2
unnamed: D26.2 (A), SW26.2
unnamed: D27.2 (A), SW27.2
unnamed: D28.2 (A), SW28.2
unnamed: D29.2 (A), SW29.2
unnamed: D30.2 (A), SW30.2
unnamed: D31.2 (A), SW31.2
unnamed: D32.2 (A), SW32.2
unnamed: D33.2 (A), SW33.2
unnamed: D34.2 (A), SW34.2
unnamed: D35.2 (A), SW35.2
unnamed: D36.2 (A), SW36.2
unnamed: D37.2 (A), SW37.2
unnamed: D38.2 (A), SW38.2
unnamed: D39.2 (A), SW39.2
unnamed: D40.2 (A), SW40.2
unnamed: D41.2 (A), SW41.2
unnamed: D42.2 (A), SW42.2
unnamed: D43.2 (A), SW43.2
unnamed: D44.2 (A), SW44.2
unnamed: D45.2 (A), SW45.2
unnamed: D46.2 (A), SW46.2
unnamed: D47.2 (A), SW47.2
unnamed: D48.2 (A), SW48.2
unnamed: D49.2 (A), SW49.2
unnamed: D50.2 (A), SW50.2
unnamed: D51.2 (A), SW51.2
unnamed: D52.2 (A), SW52.2
unnamed: D53.2 (A), SW53.2
unnamed: D54.2 (A), SW54.2
unnamed: D55.2 (A), SW55.2
unnamed: D56.2 (A), SW56.2
unnamed: D57.2 (A), SW57.2
unnamed: D58.2 (A), SW58.2
unnamed: D59.2 (A), SW59.2
unnamed: D60.2 (A), SW60.2
unnamed: D61.2 (A), SW61.2
unnamed: D62.2 (A), SW62.2
unnamed: D63.2 (A), SW63.2
unnamed: D64.2 (A), SW64.2
unnamed: D65.2 (A), SW66.2
unnamed: D65.1 (K), D66.1 (K), D71.1 (K), D77.1 (K), U4.8 (P4)
unnamed: D66.2 (A), SW67.2
unnamed: D67.2 (A), SW68.2
unnamed: D67.1 (K), D72.1 (K), D73.1 (K), D78.1 (K), U4.9 (P5)
unnamed: D68.2 (A), SW69.2
unnamed: D68.1 (K), D74.1 (K), D79.1 (K), U4.10 (P6)
unnamed: D69.2 (A), SW70.2
unnamed: D69.1 (K), D75.1 (K), D80.1 (K), D81.1 (K), U4.11 (P7)
unnamed: D70.2 (A), SW71.2
unnamed: D70.1 (K), D76.1 (K), D82.1 (K), U4.13 (P10)
unnamed: D71.2 (A), SW72.2
unnamed: D72.2 (A), SW73.2
unnamed: D73.2 (A), SW74.2
unnamed: D74.2 (A), SW75.2
unnamed: D75.2 (A), SW76.2
unnamed: D76.2 (A), SW77.2
unnamed: D77.2 (A), SW78.2
unnamed: D78.2 (A), SW79.2
unnamed: D79.2 (A), SW80.2
unnamed: D80.2 (A), SW81.2
unnamed: D81.2 (A), SW82.2
unnamed: D82.2 (A), SW83.2
unnamed: SK6812_MINI_E1.3 (DOUT), SK6812_MINI_E2.1 (DIN)
unnamed: SK6812_MINI_E2.3 (DOUT), SK6812_MINI_E3.1 (DIN)
unnamed: SK6812_MINI_E3.3 (DOUT), SK6812_MINI_E4.1 (DIN)
unnamed: SK6812_MINI_E4.3 (DOUT), SK6812_MINI_E5.1 (DIN)
unnamed: SK6812_MINI_E5.3 (DOUT), SK6812_MINI_E6.1 (DIN)
unnamed: SK6812_MINI_E6.3 (DOUT), SK6812_MINI_E7.1 (DIN)
unnamed: SK6812_MINI_E7.3 (DOUT), SK6812_MINI_E8.1 (DIN)
unnamed: SK6812_MINI_E8.3 (DOUT), SK6812_MINI_E9.1 (DIN)
unnamed: SK6812_MINI_E9.3 (DOUT), SK6812_MINI_E10.1 (DIN)
unnamed: SK6812_MINI_E10.3 (DOUT), SK6812_MINI_E11.1 (DIN)
unnamed: SK6812_MINI_E11.3 (DOUT), SK6812_MINI_E12.1 (DIN)
unnamed: SK6812_MINI_E12.3 (DOUT), SK6812_MINI_E13.1 (DIN)
unnamed: SK6812_MINI_E13.3 (DOUT), SK6812_MINI_E14.1 (DIN)
unnamed: SK6812_MINI_E14.3 (DOUT), SK6812_MINI_E15.1 (DIN)
unnamed: SK6812_MINI_E15.3 (DOUT), SK6812_MINI_E16.1 (DIN)
unnamed: SK6812_MINI_E16.3 (DOUT), SK6812_MINI_E17.1 (DIN)
unnamed: SK6812_MINI_E17.3 (DOUT), SK6812_MINI_E18.1 (DIN)
unnamed: SK6812_MINI_E18.3 (DOUT), SK6812_MINI_E19.1 (DIN)
unnamed: SK6812_MINI_E19.3 (DOUT), SK6812_MINI_E20.1 (DIN)
unnamed: SK6812_MINI_E20.3 (DOUT), SK6812_MINI_E21.1 (DIN)
unnamed: SK6812_MINI_E21.3 (DOUT), SK6812_MINI_E22.1 (DIN)
unnamed: SK6812_MINI_E22.3 (DOUT), SK6812_MINI_E23.1 (DIN)
unnamed: SK6812_MINI_E23.3 (DOUT), SK6812_MINI_E24.1 (DIN)
unnamed: SK6812_MINI_E24.3 (DOUT), SK6812_MINI_E25.1 (DIN)
unnamed: SK6812_MINI_E25.3 (DOUT), SK6812_MINI_E26.1 (DIN)
unnamed: SK6812_MINI_E26.3 (DOUT), SK6812_MINI_E27.1 (DIN)
unnamed: SK6812_MINI_E27.3 (DOUT), SK6812_MINI_E28.1 (DIN)
unnamed: SK6812_MINI_E28.3 (DOUT), SK6812_MINI_E29.1 (DIN)
unnamed: SK6812_MINI_E29.3 (DOUT), SK6812_MINI_E30.1 (DIN)
unnamed: SK6812_MINI_E30.3 (DOUT), SK6812_MINI_E31.1 (DIN)
unnamed: SK6812_MINI_E31.3 (DOUT), SK6812_MINI_E32.1 (DIN)
unnamed: SK6812_MINI_E32.3 (DOUT), SK6812_MINI_E33.1 (DIN)
unnamed: SK6812_MINI_E33.3 (DOUT), SK6812_MINI_E34.1 (DIN)
unnamed: SK6812_MINI_E34.3 (DOUT), SK6812_MINI_E35.1 (DIN)
unnamed: SK6812_MINI_E35.3 (DOUT), SK6812_MINI_E36.1 (DIN)
unnamed: SK6812_MINI_E36.3 (DOUT), SK6812_MINI_E37.1 (DIN)
unnamed: SK6812_MINI_E37.3 (DOUT), SK6812_MINI_E38.1 (DIN)
unnamed: SK6812_MINI_E38.3 (DOUT), SK6812_MINI_E39.1 (DIN)
unnamed: SK6812_MINI_E39.3 (DOUT), SK6812_MINI_E40.1 (DIN)
unnamed: SK6812_MINI_E40.3 (DOUT), SK6812_MINI_E41.1 (DIN)
unnamed: SK6812_MINI_E41.3 (DOUT), SK6812_MINI_E42.1 (DIN)
unnamed: SK6812_MINI_E42.3 (DOUT), SK6812_MINI_E43.1 (DIN)
unnamed: SK6812_MINI_E43.3 (DOUT), SK6812_MINI_E44.1 (DIN)
unnamed: SK6812_MINI_E44.3 (DOUT), SK6812_MINI_E45.1 (DIN)
unnamed: SK6812_MINI_E45.3 (DOUT), SK6812_MINI_E46.1 (DIN)
unnamed: SK6812_MINI_E46.3 (DOUT), SK6812_MINI_E47.1 (DIN)
unnamed: SK6812_MINI_E47.3 (DOUT), SK6812_MINI_E48.1 (DIN)
unnamed: SK6812_MINI_E48.3 (DOUT), SK6812_MINI_E49.1 (DIN)
unnamed: SK6812_MINI_E49.3 (DOUT), SK6812_MINI_E50.1 (DIN)
unnamed: SK6812_MINI_E50.3 (DOUT), SK6812_MINI_E51.1 (DIN)
unnamed: SK6812_MINI_E51.3 (DOUT), SK6812_MINI_E52.1 (DIN)
unnamed: SK6812_MINI_E52.3 (DOUT), SK6812_MINI_E53.1 (DIN)
unnamed: SK6812_MINI_E53.3 (DOUT), SK6812_MINI_E54.1 (DIN)
unnamed: SK6812_MINI_E54.3 (DOUT), SK6812_MINI_E55.1 (DIN)
unnamed: SK6812_MINI_E55.3 (DOUT), SK6812_MINI_E56.1 (DIN)
unnamed: SK6812_MINI_E56.3 (DOUT), SK6812_MINI_E57.1 (DIN)
unnamed: SK6812_MINI_E57.3 (DOUT), SK6812_MINI_E58.1 (DIN)
unnamed: SK6812_MINI_E58.3 (DOUT), SK6812_MINI_E59.1 (DIN)
unnamed: SK6812_MINI_E59.3 (DOUT), SK6812_MINI_E60.1 (DIN)
unnamed: SK6812_MINI_E60.3 (DOUT), SK6812_MINI_E61.1 (DIN)
unnamed: SK6812_MINI_E61.3 (DOUT), SK6812_MINI_E62.1 (DIN)
unnamed: SK6812_MINI_E62.3 (DOUT), SK6812_MINI_E63.1 (DIN)
unnamed: SK6812_MINI_E63.3 (DOUT), SK6812_MINI_E64.1 (DIN)
unnamed: SK6812_MINI_E75.1 (DIN), SK6812_MINI_E82.3 (DOUT)
unnamed: SK6812_MINI_E75.3 (DOUT), SK6812_MINI_E81.1 (DIN)
unnamed: SK6812_MINI_E76.1 (DIN), SK6812_MINI_E81.3 (DOUT)
unnamed: SK6812_MINI_E76.3 (DOUT), SK6812_MINI_E87.1 (DIN)
unnamed: SK6812_MINI_E77.1 (DIN), SK6812_MINI_E83.3 (DOUT)
unnamed: SK6812_MINI_E77.3 (DOUT), SK6812_MINI_E88.1 (DIN)
unnamed: SK6812_MINI_E78.1 (DIN), SK6812_MINI_E89.3 (DOUT)
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

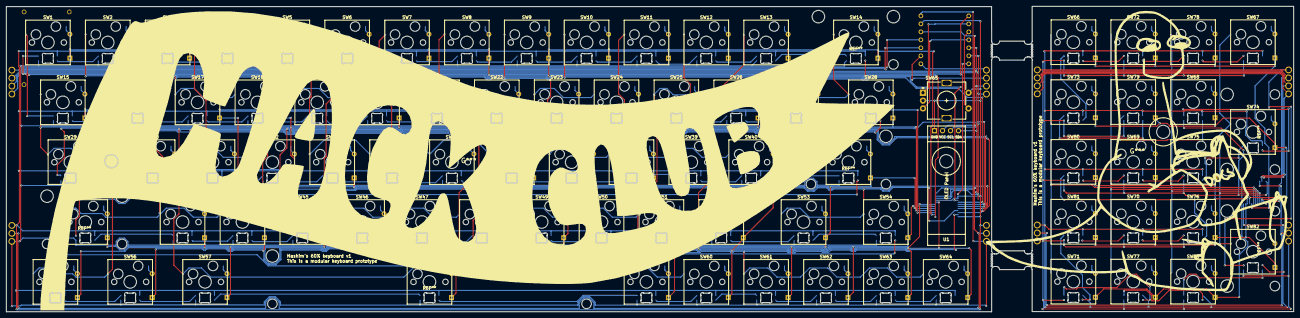
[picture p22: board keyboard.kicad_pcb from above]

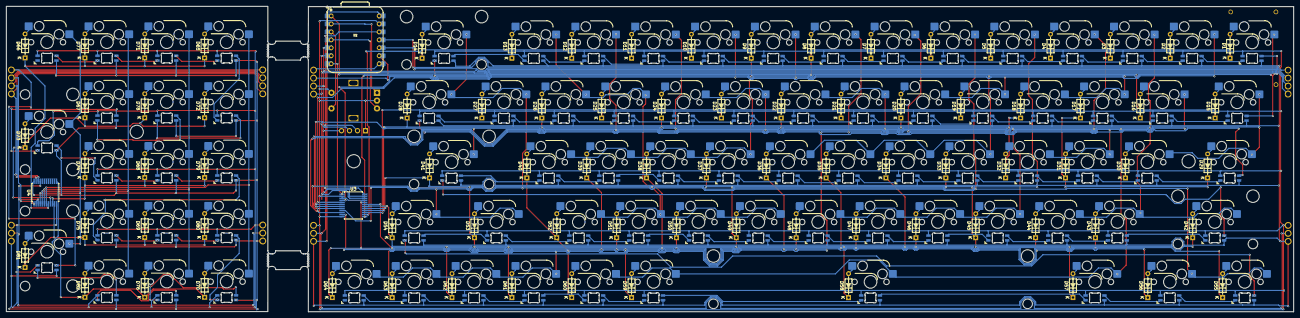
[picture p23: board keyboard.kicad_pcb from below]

Board: 2 copper layers, 409.7 x 97.2 mm, 260 parts (85 on the bottom side), 208 nets.

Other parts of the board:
TP4056_Type_C_Charger: Charger; Pogo_Pins_4P

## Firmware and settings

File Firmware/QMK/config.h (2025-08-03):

#pragma once

// Matrix configuration - matches info.json and layout
#define MATRIX_ROWS 5   
#define MATRIX_COLS 18  

#define CUSTOM_MATRIX

#define I2C_DRIVER I2CD1
#define I2C1_SDA_PIN GP4     
#define I2C1_SCL_PIN GP5     
#define I2C1_TIMINGR_PRESC 0U
#define I2C1_TIMINGR_SCLDEL 3U
#define I2C1_TIMINGR_SDADEL 1U
#define I2C1_TIMINGR_SCLH 3U
#define I2C1_TIMINGR_SCLL 9U


// Main keyboard: A pins to GND (A2=0, A1=0, A0=0) = 0x20
// Numpad: A pins to 3.3V (A2=1, A1=1, A0=1) = 0x27
#define PCF8575_MAIN_ADDR   0x20    // 64-key main matrix (8x8)
#define PCF8575_NUMPAD_ADDR 0x27    // 20-key numpad matrix (4x5)    

#define PCF8575_MAIN_INT_PIN   GP11   
#define PCF8575_NUMPAD_INT_PIN GP14   

// Main RGB configuration (first chain)
// RGB configuration
#define RGBLIGHT_LED_COUNT 82       // Total LEDs (64 main + 18 numpad)
#define WS2812_DI_PIN GP2           // Main RGB data pin (64 LEDs)

// Numpad RGB configuration (separate chain)
#define WS2812_NUMPAD_DI_PIN GP15   // Numpad RGB data pin (18 LEDs)

// RGB configuration
#define RGBLIGHT_EFFECT_RAINBOW_MOOD
#define RGBLIGHT_EFFECT_RAINBOW_SWIRL
#define RGBLIGHT_EFFECT_SNAKE
#define RGBLIGHT_EFFECT_KNIGHT
#define RGBLIGHT_EFFECT_CHRISTMAS
#define RGBLIGHT_EFFECT_STATIC_GRADIENT
#define RGBLIGHT_EFFECT_RGB_TEST
#define RGBLIGHT_EFFECT_ALTERNATING
#define RGBLIGHT_EFFECT_TWINKLE

// WS2812 driver configuration
#define WS2812_EXTERNAL_PULLUP      // If needed for signal integrity

// SK6812 MINI-E notes:
// - Compatible with WS2812 driver
// - Uses same protocol and timing
// - If LEDs don't work properly, try adjusting WS2812_TIMING

#define OLED_DISPLAY_128X64
#define OLED_TIMEOUT 60000

// Encoder Configuration  
#define ENCODER_RESOLUTION 4

// Debounce
#define DEBOUNCE 5

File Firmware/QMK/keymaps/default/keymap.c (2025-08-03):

// Layer 0: Base layer
// Layer 1: Function layer
// Layer 2: RGB/System layer

#include QMK_KEYBOARD_H

static bool numpad_rgb_enabled = true;
static uint8_t numpad_rgb_mode = 0;


typedef enum {
    NUMPAD_RGB_OFF = 0,
    NUMPAD_RGB_SOLID,
    NUMPAD_RGB_BREATHING,
    NUMPAD_RGB_RAINBOW,
    NUMPAD_RGB_MODES_COUNT
} numpad_rgb_mode_t;

enum custom_keycodes {
    RGB_TOG_MAIN = SAFE_RANGE,
    RGB_TOG_NUMPAD,
    RGB_MOD_NUMPAD,    
    RGB_HUI_NUMPAD,    
    RGB_HUD_NUMPAD,    
    RGB_VAI_NUMPAD,    
    RGB_VAD_NUMPAD,    
    OLED_TOG
};

enum layer_names {
    _BASE,
    _FN,
    _RGB
};

static void numpad_rgb_update(void) {
    // Simplified RGB function using standard QMK RGB
    if (!numpad_rgb_enabled) {
        rgblight_disable();
    } else {
        rgblight_enable();
        switch (numpad_rgb_mode) {
            case NUMPAD_RGB_SOLID:
                rgblight_mode(RGBLIGHT_MODE_STATIC_LIGHT);
                break;
                
            case NUMPAD_RGB_BREATHING:
                rgblight_mode(RGBLIGHT_MODE_BREATHING);
                break;
                
            case NUMPAD_RGB_RAINBOW:
                rgblight_mode(RGBLIGHT_MODE_RAINBOW_MOOD);
                break;
                
            default:
                rgblight_disable();
                break;
        }
    }
}

// Toggle numpad RGB
static void numpad_rgb_toggle(void) {
    numpad_rgb_enabled = !numpad_rgb_enabled;
    numpad_rgb_update();
}

// Cycle numpad RGB mode
static void numpad_rgb_mode_step(void) {
    numpad_rgb_mode = (numpad_rgb_mode + 1) % NUMPAD_RGB_MODES_COUNT;
    numpad_rgb_update();
}
const uint16_t PROGMEM keymaps[][MATRIX_ROWS][MATRIX_COLS] = {

    [_BASE] = LAYOUT(
        // Main keyboard (60% layout)
        KC_ESC,  KC_1,    KC_2,    KC_3,    KC_4,    KC_5,    KC_6,    KC_7,    KC_8,    KC_9,    KC_0,    KC_MINS, KC_EQL,  KC_BSPC,
        KC_TAB,  KC_Q,    KC_W,    KC_E,    KC_R,    KC_T,    KC_Y,    KC_U,    KC_I,    KC_O,    KC_P,    KC_LBRC, KC_RBRC, KC_BSLS,
        KC_CAPS, KC_A,    KC_S,    KC_D,    KC_F,    KC_G,    KC_H,    KC_J,    KC_K,    KC_L,    KC_SCLN, KC_QUOT, KC_ENT,
        KC_LSFT, KC_Z,    KC_X,    KC_C,    KC_V,    KC_B,    KC_N,    KC_M,    KC_COMM, KC_DOT,  KC_SLSH, KC_RSFT, KC_UP,
        KC_LCTL, KC_LGUI, KC_LALT, KC_SPC,  KC_RALT, MO(_FN), KC_LEFT, KC_DOWN, KC_RGHT, KC_HOME, KC_END,
        
        // Numpad
        KC_NUM,  KC_PSLS, KC_PAST, KC_PMNS,
        KC_P7,   KC_P8,   KC_P9,   KC_PPLS,
        KC_P4,   KC_P5,   KC_P6,
        KC_P1,   KC_P2,   KC_P3,   KC_PENT,
        KC_P0,   KC_PDOT, KC_DEL
    ),

    [_FN] = LAYOUT(
        // Main keyboard function layer
        KC_GRV,  KC_F1,   KC_F2,   KC_F3,   KC_F4,   KC_F5,   KC_F6,   KC_F7,   KC_F8,   KC_F9,   KC_F10,  KC_F11,  KC_F12,  KC_DEL,
        KC_TRNS, KC_TRNS, KC_UP,   KC_TRNS, KC_TRNS, KC_TRNS, KC_TRNS, KC_TRNS, KC_INS,  KC_TRNS, KC_PSCR, KC_SCRL, KC_PAUS, KC_TRNS,
        KC_TRNS, KC_LEFT, KC_DOWN, KC_RGHT, KC_TRNS, KC_TRNS, KC_TRNS, KC_TRNS, KC_HOME, KC_PGUP, KC_TRNS, KC_TRNS, KC_TRNS,
        KC_TRNS, KC_TRNS, KC_TRNS, KC_TRNS, KC_TRNS, KC_TRNS, KC_TRNS, KC_TRNS, KC_END,  KC_PGDN, KC_TRNS, KC_TRNS, KC_VOLU,
        KC_TRNS, KC_TRNS, KC_TRNS, KC_TRNS, KC_TRNS, MO(_RGB), KC_MPRV, KC_VOLD, KC_MNXT, KC_MPLY, KC_MUTE,
        
        // Numpad function layer
        KC_TRNS, KC_TRNS, KC_TRNS, KC_TRNS,
        KC_HOME, KC_UP,   KC_PGUP, KC_TRNS,
        KC_LEFT, KC_TRNS, KC_RGHT,
        KC_END,  KC_DOWN, KC_PGDN, KC_TRNS,
        KC_INS,  KC_DEL,  KC_TRNS
    ),

    [_RGB] = LAYOUT(
        // RGB and system controls
        QK_BOOT, KC_TRNS, KC_TRNS, KC_TRNS, KC_TRNS, KC_TRNS, KC_TRNS, KC_TRNS, KC_TRNS, KC_TRNS, KC_TRNS, KC_TRNS, KC_TRNS, KC_TRNS,
        KC_TRNS, RGB_TOG, RGB_MOD, RGB_HUI, RGB_HUD, RGB_SAI, RGB_SAD, RGB_VAI, RGB_VAD, KC_TRNS, KC_TRNS, KC_TRNS, KC_TRNS, KC_TRNS,
        KC_TRNS, RGB_TOG_MAIN, RGB_TOG_NUMPAD, RGB_MOD_NUMPAD, RGB_HUI_NUMPAD, RGB_HUD_NUMPAD, RGB_VAI_NUMPAD, RGB_VAD_NUMPAD, KC_TRNS, KC_TRNS, KC_TRNS, KC_TRNS, KC_TRNS,
        KC_TRNS, KC_TRNS, KC_TRNS, KC_TRNS, KC_TRNS, KC_TRNS, KC_TRNS, KC_TRNS, KC_TRNS, KC_TRNS, KC_TRNS, KC_TRNS, KC_TRNS,
        KC_TRNS, KC_TRNS, KC_TRNS, KC_TRNS, KC_TRNS, KC_TRNS, KC_TRNS, KC_TRNS, KC_TRNS, KC_TRNS, KC_TRNS,
        
        // Numpad RGB layer
        KC_TRNS, KC_TRNS, KC_TRNS, KC_TRNS,
        KC_TRNS, KC_TRNS, KC_TRNS, KC_TRNS,
        KC_TRNS, KC_TRNS, KC_TRNS,
        KC_TRNS, KC_TRNS, KC_TRNS, KC_TRNS,
        KC_TRNS, KC_TRNS, KC_TRNS
    )
};

// Encoder mapping
#if defined(ENCODER_MAP_ENABLE)
const uint16_t PROGMEM encoder_map[][NUM_ENCODERS][2] = {
    [_BASE] = { ENCODER_CCW_CW(KC_VOLD, KC_VOLU) },
    [_FN]   = { ENCODER_CCW_CW(KC_MPRV, KC_MNXT) },
    [_RGB]  = { ENCODER_CCW_CW(RGB_VAD, RGB_VAI) },
};
#endif

// OLED display code
#ifdef OLED_ENABLE
bool oled_task_user(void) {
    // Host keyboard layer status
    oled_write_P(PSTR("Layer: "), false);
    switch (get_highest_layer(layer_state)) {
        case _BASE:
            oled_write_P(PSTR("Base\n"), false);
            break;
        case _FN:
            oled_write_P(PSTR("Function\n"), false);
            break;
        case _RGB:
            oled_write_P(PSTR("RGB/System\n"), false);
            break;
        default:
            oled_write_P(PSTR("Undefined\n"), false);
    }

    // Host keyboard LED status
    led_t led_state = host_keyboard_led_state();
    oled_write_P(led_state.num_lock ? PSTR("NUM ") : PSTR("    "), false);
    oled_write_P(led_state.caps_lock ? PSTR("CAP ") : PSTR("    "), false);
    oled_write_P(led_state.scroll_lock ? PSTR("SCR ") : PSTR("    "), false);

    return false;
}
#endif

// Initialize numpad RGB on startup
void keyboard_post_init_user(void) {
    // Initialize numpad RGB to solid color
    numpad_rgb_mode = NUMPAD_RGB_SOLID;
    numpad_rgb_update();
}

// Housekeeping task for numpad RGB animations
void housekeeping_task_user(void) {
    // Update numpad RGB if enabled and in animated mode
    if (numpad_rgb_enabled && (numpad_rgb_mode == NUMPAD_RGB_BREATHING || numpad_rgb_mode == NUMPAD_RGB_RAINBOW)) {
        static uint32_t last_update = 0;
        if (timer_elapsed32(last_update) > 50) { // Update every 50ms
            numpad_rgb_update();
            last_update = timer_read32();
        }
    }
}
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

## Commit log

2025-08-02 add BOM
    [BOM.csv]
2025-08-02 update wiring
2025-08-03 add QMk firmware + updae BOM
    [BOM.csv]
2025-08-04 update BOM to include OLED
    [BOM.csv]
2025-08-05 update BOM to include diodes and leds
    [BOM.csv]
2025-08-06 update BOM to include cheaper switches + update time spent on firmware
    [BOM.csv]
